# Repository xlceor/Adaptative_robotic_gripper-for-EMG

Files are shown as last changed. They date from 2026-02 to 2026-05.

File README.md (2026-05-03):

# PROJECT KHYMERA

## Modular Robotic Prosthetic System | Functional, Scalable, Real

---

## 🚀 TL;DR

A low-cost modular robotic prosthetic system built with real hardware, real iteration, and real-world constraints.

- Dual-servo optimized gripper  
- Fully functional prototype (V0 → V2)  
- Designed for future EMG control  
- Built with 3D printing + embedded systems  

---

## 🎥 Live Demonstration

0503 (1)(1)

This is not a concept.

This is a working system:
- Real movement  
- Real grip  
- Real control  

---

## 🧠 Overview

Project KHYMERA is a modular robotic prosthetic system designed to challenge the traditional approach to upper-limb prosthetics.

Instead of replicating the human hand, this project focuses on:

- Mechanical efficiency  
- Modularity  
- Accessibility  
- Scalability toward myoelectric control  

The result is a functional robotic gripper system built through iterative engineering, not theoretical design.

---

## 🛠️ System Architecture

### ⚙️ Mechanical System

- Parallel gripper design  
- Four-bar linkage mechanism  
- Dual servo actuation  
- Geometry optimized for full range of motion  

---
### 💻 Control system

#### Control Layer
Handles smooth motion interpolation between target and current positions:
- Real-time servo control loop (~20 ms)
- Dual-servo synchronized movement

#### Communication Layer
Provides external control and monitoring:
- REST API endpoints (`/servo`, `/ping`, `/demo`)
- WiFi Access Point mode
- Server-Sent Events (SSE) for real-time streaming

#### Telemetry Layer
Streams system diagnostics to the UI:
- Simulated temperature, voltage, load, vibration, ADC
- Designed to emulate real sensor behavior

#### State Layer
Maintains and broadcasts system state:
- Target vs current angle tracking
- Real-time synchronization with UI

#### UI Integration
Designed for real-time dashboard interaction:
- Low-latency feedback via SSE
- Compatible with advanced HUD-style interfaces

### 🔩 Manufacturing

- 3D Printing (FDM):
  - PLA → structural components  
  - TPU → flexible gripping surfaces  
- Rapid prototyping workflow  

---

### 🔌 Electronics

- ESP32-based control  
- Servo motors (MG996R)  
- Power system:
  - Dual 18650 batteries  
  - DC-DC regulator (XL4016)  
- Capacitor-based stabilization  

---

## 📁 Repository Structure
/mechanical/   → CAD files (V0, V1, V2)
/firmware/     → Embedded control code

---

## 🚨 The Problem

Modern prosthetics face critical limitations:

- High cost → inaccessible to many users  
- Mechanical complexity  
- Limited adaptability  

Even open-source solutions often struggle with:

- Inefficient actuation  
- Poor force transmission  
- Overreliance on biomimicry  

---

## 💡 The Approach

KHYMERA proposes a shift in design philosophy:

**From biomimicry → functional modularity**

Instead of replicating the human hand, the system is designed as:

- A robotic gripper module  
- Mechanically efficient  
- Easy to manufacture  
- Ready for integration into larger systems  

---

## 🔁 Development Process

Built through iterative engineering:

| Version | Purpose | Result |
|---|---|---|
| V0 | Validate mechanism | Functional proof of concept |
| V1 | Integrate actuation | Improved structure, limited motion |
| V2 | Optimize geometry | Full range of motion, stable operation |

### Key Improvements

- Enhanced motion transmission  
- Improved grip using TPU surfaces  
- Structural alignment refinements  

---

## 📊 Functional Capabilities

Validated through real-world testing:

- ✔ Stable opening and closing motion  
- ✔ Reliable object gripping  
- ✔ Adaptability to different object shapes  
- ✔ Improved friction via TPU contact surfaces  

---

## 🧪 Methodology

- Experimental + technological research approach  
- Iterative prototyping  
- Direct functional testing  
- Qualitative performance evaluation  

Follows a standard engineering loop:

**Design → Build → Test → Optimize**

---

## 🚀 Why This Project Matters

- Demonstrates real engineering execution  
- Focuses on accessibility and affordability  
- Bridges mechanics, electronics, and embedded systems  
- Designed under real-world constraints, not ideal conditions  

---

## 🧭 Future Work

- EMG signal acquisition (ESP32-S3)  
- Myoelectric control system  
- Force sensing integration  
- Closed-loop control  
- Full robotic arm system  
- Advanced materials and optimization  

---

## ⚡ Quick Start

1. 3D print components (PLA + TPU)  
2. Assemble mechanical structure  
3. Upload firmware to Arduino  
4. Power with regulated ~6.2V supply  

**Recommended:** basic experience with electronics and 3D printing  

---

## 👨‍💻 Author

Carlos Osorio  
Systems Builder | Robotics | Embedded Systems | Applied Engineering  

Focused on building systems that interact with the real world.

---

## ⚠️ Disclaimer

This project is an experimental prototype and is not intended for clinical use.

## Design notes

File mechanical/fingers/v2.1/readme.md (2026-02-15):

# TPU Finger Prototype v1.1

## Purpose
TPU finger of adaptable soft-robotic gripper. 

## Geometry
Right triangle base with parallel internal bending lines to allow controlled deformation.

## Material
TPU 95A

## Comments of the version
The base model still the same that the previous version, but the external wall -the one that is in contact with the object- now has texture, adding friction and gripping capacity. Even so, the thickness of the external wall was small.
## Next Steps
Test under real-life load to meassure the resistance of the finger.

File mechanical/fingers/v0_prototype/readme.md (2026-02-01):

# TPU Finger Prototype v0

## Purpose
Initial experiment to create a compliant finger using TPU, based on observations of similar models.

## Geometry
Right triangle base with parallel internal bending lines to allow controlled deformation.

## Material
TPU 95A

## Observations
Conceptual model. The thickness is based on approximations, but actual performance and future iterations will depend on prototyping.

## Next Step
3D print the model to test performance

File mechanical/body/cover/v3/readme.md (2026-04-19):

# Cover v3

## Purpose
Close the design and keep all internal components hidden, improving the aesthetics.

## Geometry
The shape was designed based on the body's design. It was divided into three parts, each corresponding to a section of the body. This allows for quicker access to a specific component if needed, without having to open the entire device.

## Material
PLA for testing

## Comments of the version
Due to time reasons, the body itself was not updated for the mounting points. In this version self-tapping screws was used to close the device without reprinting all the design. Also, some slots was added for better ventilation on components as the buck, and the servos, but also to keep acces to some components without removing the case, like the switch and the alimentation of ESP32.

## Next Steps
Update main body, verify issues, and roceed remodeling

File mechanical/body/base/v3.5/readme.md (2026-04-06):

# Base v3.5

## Purpose
Base of the four-bar linkage. It serves as a support and for storing the electronics, including the servos, buck converter, and MCU.

## Geometry
The shape was designed in base of the structure of 2 servos tandem-mounted and the module Xl4016, with sections on the sides to store MCU, power supply board, and the batteries

## Material
PLA for testing

## Comments of the version
Integred the new sections on this version. It appears to work fine. But, the reduction still as a problem. I think the best way to proceed is redesign the original "box" to reduce the space between servos, print gears for each one and conect both mechanically, and redesign the finger to adapt to the new rotation.

## Next Steps
Verify issues, and proceed remodeling

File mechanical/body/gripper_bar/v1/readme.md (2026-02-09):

# Linkage bar v1

## Purpose
link base that connects the TPU finger to the base via the mechanism.

## Geometry
The shape was designed to reduce weight while maintaining strength. 

## Material
Currently PLA. In future versions, the material will be remplaced with PETG

## Comments of the version
This model is the first to be tested under real-world conditions. Unlike the previous version, the center-to-center distance is greater for increased gripping capacity. Additionally, the number of screw holes has been increased to two, eliminating the problem of the previous version (where the head rotated using the center screw as an axis). Furthermore, the head geometry has been adapted to reduce weight while maintaining strength.

## Next Steps
Keep testing to see the response of the material under weight and load.

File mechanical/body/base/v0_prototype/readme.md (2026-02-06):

# Base v0

## Purpose
Base of the four-bar linkage. It serves as a support and for storing the electronics, including the servo.

## Geometry
The shape was designed to priorize stability. In this version, the base only acts as a support for prototyping.

## Material
PLA or PETG, depending on testing

## Observations
Conceptual model. The design are not tested on real life. I'll adjust the lenght and shape depending on results of testing
## Next Step
3D print the model to test shape and validate size.

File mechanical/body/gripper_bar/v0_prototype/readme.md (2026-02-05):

# Linkage bar v0

## Purpose
Initial link base that connects the TPU finger to the base via the mechanism.

## Geometry
The shape was designed to reduce weight while maintaining strength.

## Material
PLA or PETG, depending on testing

## Observations
Conceptual model. I'll adjust the form to be more strong and use less filament in future versions.
## Next Step
3D print the model to test performance

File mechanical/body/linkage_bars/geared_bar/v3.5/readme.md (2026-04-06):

# Geared bars v3.5

## Purpose
principal bars of the mechanism. Translates the servo output to the open/closing mechanism of the gripper. 

## Geometry
Due to the transmission is located in the rear area, while mantaining the same geometry, it can provide a bigger range of motion.

## Material
PLA for testing

## Comments of the version
In this version, I increased the height of the slot of the screw to provide more height, and prevent the mechanism from getting stuck
## Next Steps

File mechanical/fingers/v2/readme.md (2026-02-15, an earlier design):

# TPU Finger Prototype v1.1

## Purpose
TPU finger of adaptable soft-robotic gripper. 

## Geometry
Right triangle base with parallel internal bending lines to allow controlled deformation.

## Material
TPU 95A

## Comments of the version
Based on the previous observations, the stiffness of the finger was reduced by making the internal walls thinner. Also, the upper tip was rounded, reducing sharpness and the filament used. Even so, the wall used to grip objects was flat, reducing gripping ability. 
## Next Steps
Give the external wall texture to add gripping capacity

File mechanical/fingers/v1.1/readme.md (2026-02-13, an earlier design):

# TPU Finger Prototype v1.1

## Purpose
TPU finger of adaptable soft-robotic gripper. 

## Geometry
Right triangle base with parallel internal bending lines to allow controlled deformation.

## Material
TPU 95A

## Comments of the version
According to observations, the finger proved to be quite rigid, primarily due to the support lines parallel to the longer leg of the triangle, which is the area where the object is gripped. In this version, the orientation, number, and thickness of the parallel lines were modified, tilting them at a 50-degree angle to the base, allowing for controlled deformation. However, this version still exhibits considerable rigidity, causing more fragile objects to tend to break or deform when the claw closes. Also, the upper tip can be somewhat sharp and still represents wasted material.

## Next Steps
Adjust the thickness of the internal walls to reduce rigidity, and round the upper tip.

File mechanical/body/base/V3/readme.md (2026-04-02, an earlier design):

# Base v3

## Purpose
Base of the four-bar linkage. It serves as a support and for storing the electronics, including the servos and MCU.

## Geometry
The shape was designed in base of the structure of 2 servos tandem-mounted and the module Xl4016.

## Material
PLA for testing

## Comments of the version
The total torque was insufficient for the aplication needed. So, the design was remodeled based on 2 servos working together, hopefully multiplying the torque by two.
## Next Steps
Adapt the model to manage all the electronics

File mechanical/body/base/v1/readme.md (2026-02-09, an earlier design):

# Base v1

## Purpose
Base of the four-bar linkage. It serves as a support and for storing the electronics, including the servo.

## Geometry
The shape was designed in base of the structure of the servo, to link easily and mantain streght.

## Material
PLA or PETG, depending on testing

## Comments of the version
As readed before, the shape was modeled in base of the servomotor, a MG996R, to fit well on the servo and let the servo output at the base level of the piece. The piece was designed for use gears.
## Next Steps
Adapt the model to add stability.

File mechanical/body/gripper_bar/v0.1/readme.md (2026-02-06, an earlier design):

# Linkage bar v0.1

## Purpose
link base that connects the TPU finger to the base via the mechanism.

## Geometry
The shape was designed to reduce weight while maintaining strength. 

## Material
PLA or PETG, depending on testing

## Observations
Unlike the previous model, this version consists of two separate pieces for improved printing. The pieces are connected by a screw for added stability. Additionally, the head width has been reduced for compatibility with screws.

## Next Step
3D print the model to test performance

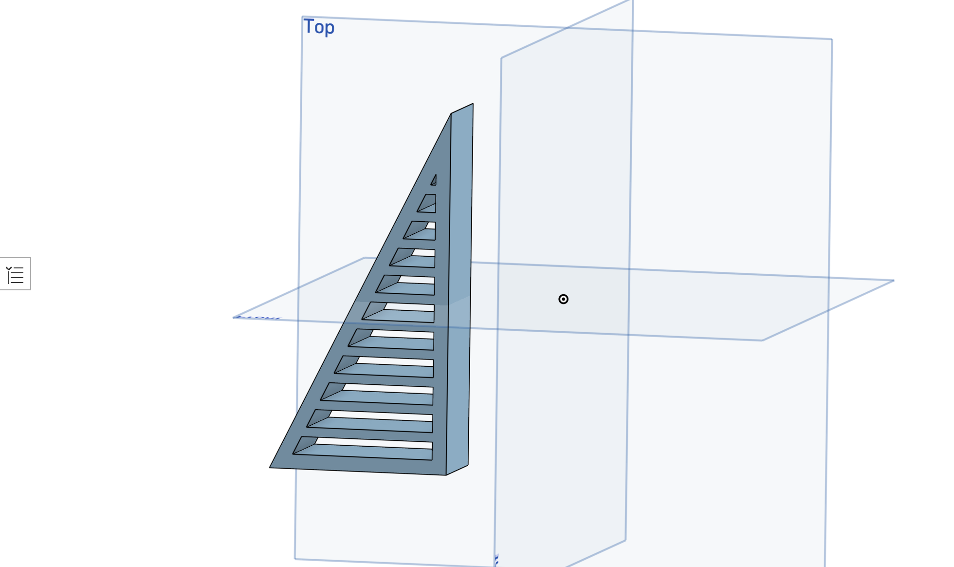
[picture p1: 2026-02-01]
mechanical/fingers/v0_prototype/screenshot.png

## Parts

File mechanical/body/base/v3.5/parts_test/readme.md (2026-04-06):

# Base v3.5 - part test

## Purpose
New section of the base that will store the logic. There, will be stored the ESP32 as MCU, and a custom welded board to manage the power supply

## Geometry
The shape was designed in base of the structure of the ESP32-S3 wroom, and a custom board. Also, a slot will be added to power the ESP32 and re-program. 

## Material
PLA for testing

## Comments of the version
These are two tests. In the first one, I didn't realize that a wall was blocking the ESP32's entry because the antenna was sticking out. So I remodel, and the second test worked correctly.

## Next Steps
Add the module to the base

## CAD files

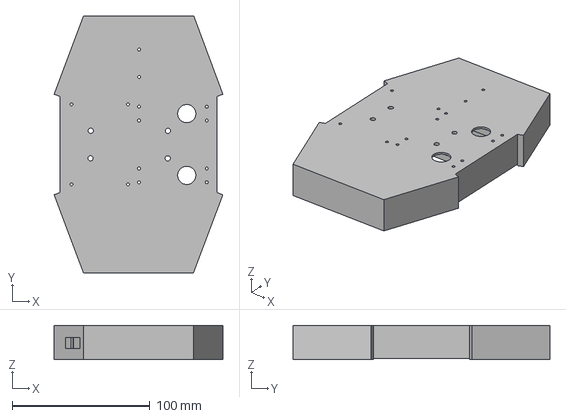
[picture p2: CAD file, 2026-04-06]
mechanical/body/base/v3.5/base.step
122.4 x 186.4 x 25.0 mm

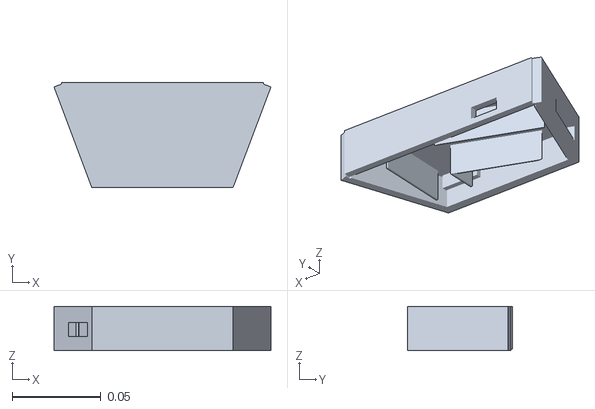
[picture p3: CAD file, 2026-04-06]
mechanical/body/base/v3.5/parts_test/test_2.stl
0.122 x 0.0592 x 0.025

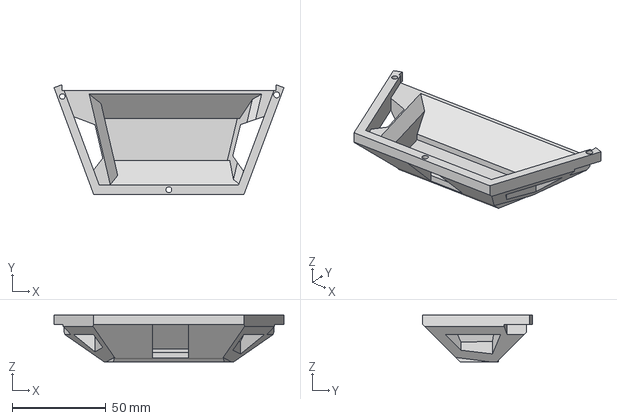
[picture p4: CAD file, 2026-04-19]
mechanical/body/cover/v3/left.step
122.4 x 58.3 x 25.0 mm

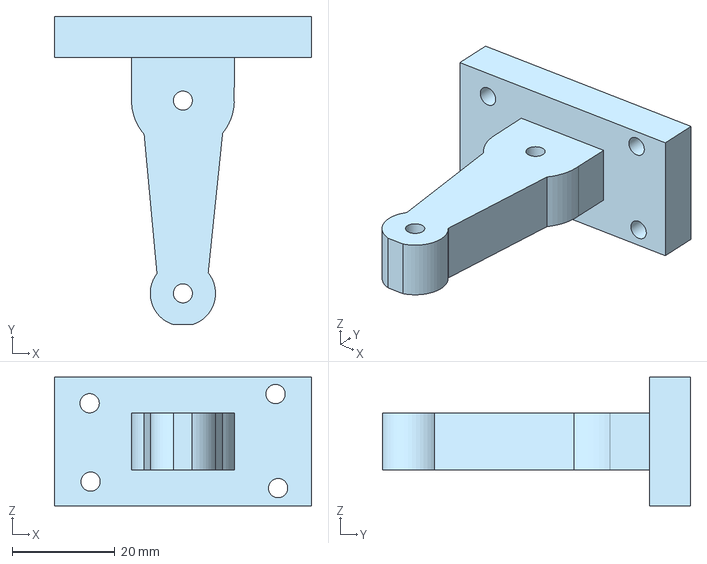
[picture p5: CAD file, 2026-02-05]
mechanical/body/gripper_bar/v0_prototype/linkage_bar.step
50.0 x 60.0 x 25.0 mm

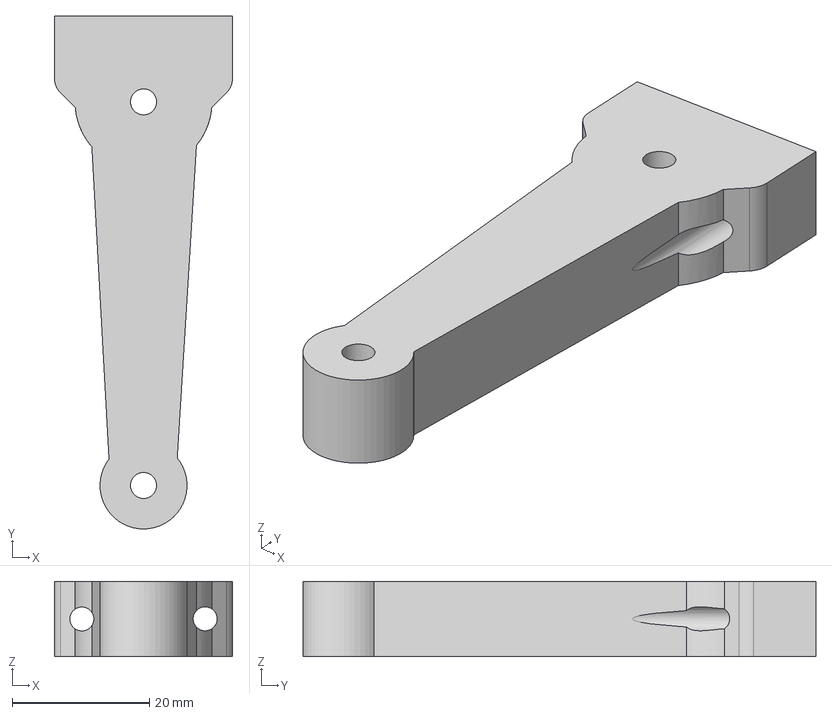
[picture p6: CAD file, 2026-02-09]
mechanical/body/gripper_bar/v1/body.step
26.0 x 74.9 x 11.0 mm

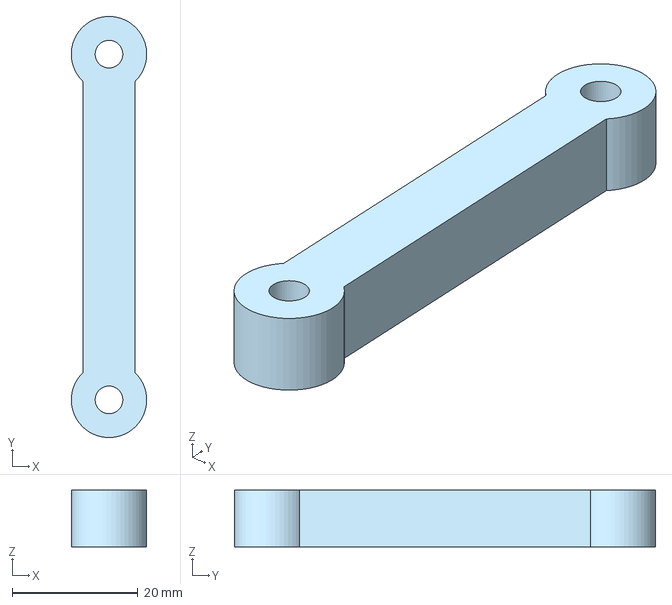
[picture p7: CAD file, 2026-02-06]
mechanical/body/linkage_bars/support_bar/v0_prototype/support_bar.step
12.0 x 67.0 x 9.00 mm

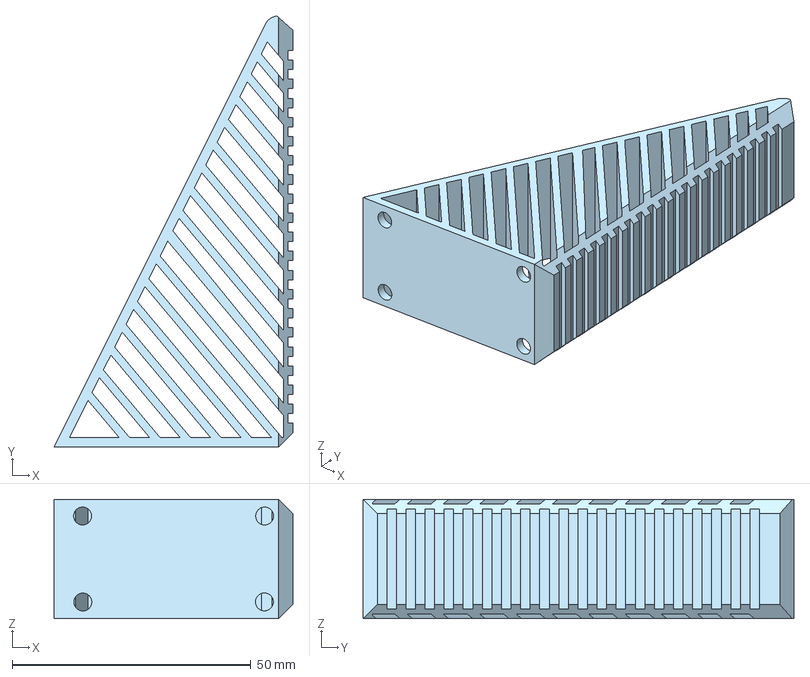
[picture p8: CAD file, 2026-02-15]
mechanical/fingers/v2.1/finger.step
50.0 x 90.2 x 25.0 mm

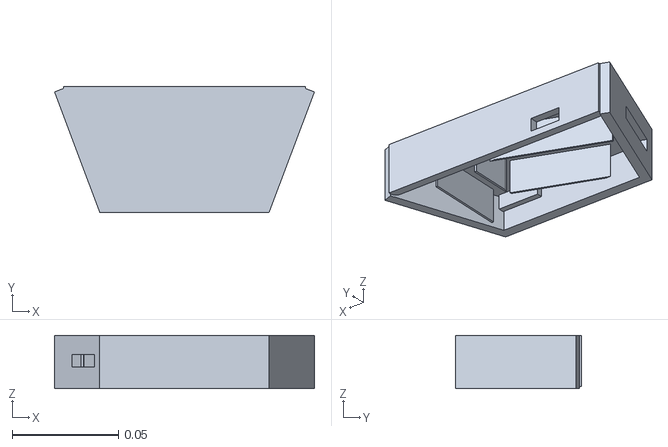
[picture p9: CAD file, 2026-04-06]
mechanical/body/base/v3.5/parts_test/test_1.stl
0.122 x 0.0592 x 0.025

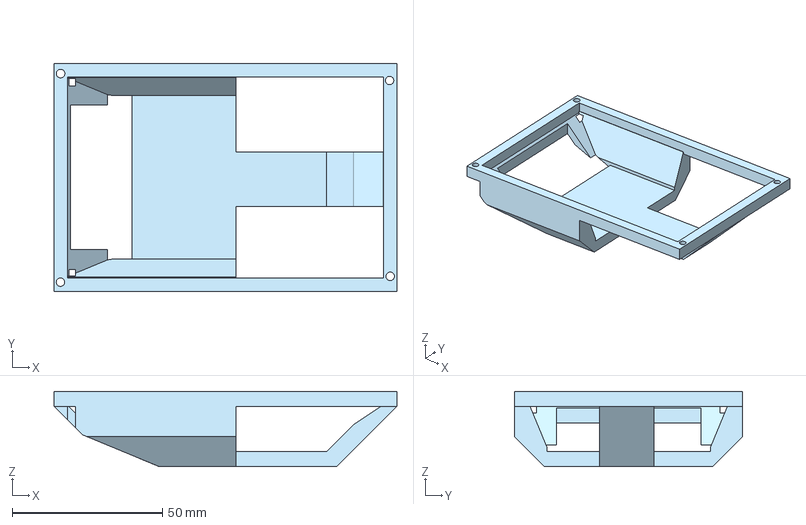
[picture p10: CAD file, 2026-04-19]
mechanical/body/cover/v3/center.step
114.0 x 75.8 x 25.0 mm

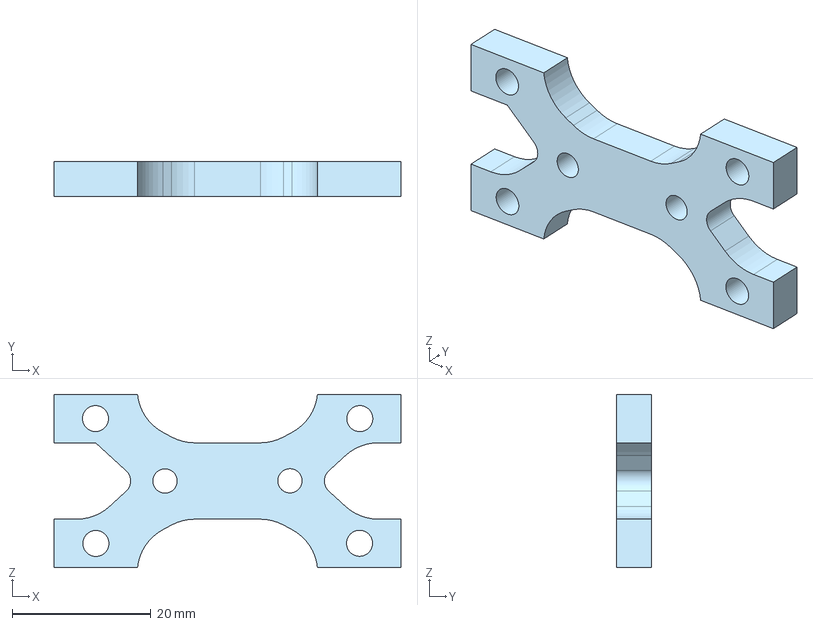
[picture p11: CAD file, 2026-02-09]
mechanical/body/gripper_bar/v1/head.step
50.0 x 5.00 x 25.0 mm

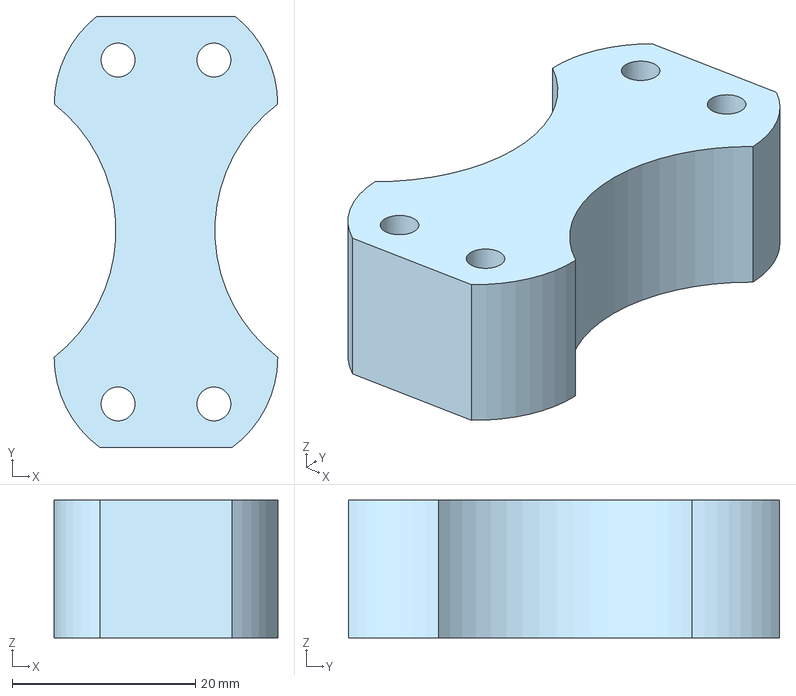
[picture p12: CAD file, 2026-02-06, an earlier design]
mechanical/body/base/v0_prototype/base.step
24.4 x 47.0 x 15.0 mm

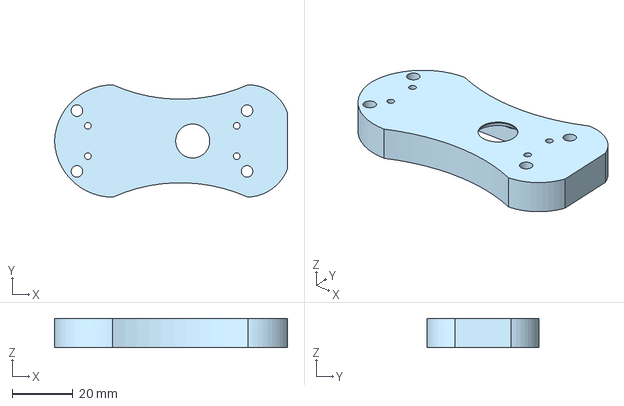
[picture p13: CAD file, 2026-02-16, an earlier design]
mechanical/body/base/v1.5/base.step
76.7 x 37.0 x 9.60 mm

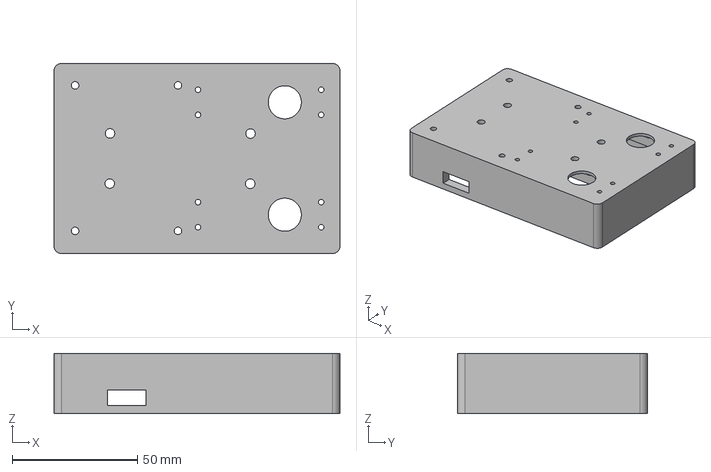
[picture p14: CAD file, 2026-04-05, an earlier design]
mechanical/body/base/v3.1/base.step
114.0 x 75.8 x 24.0 mm

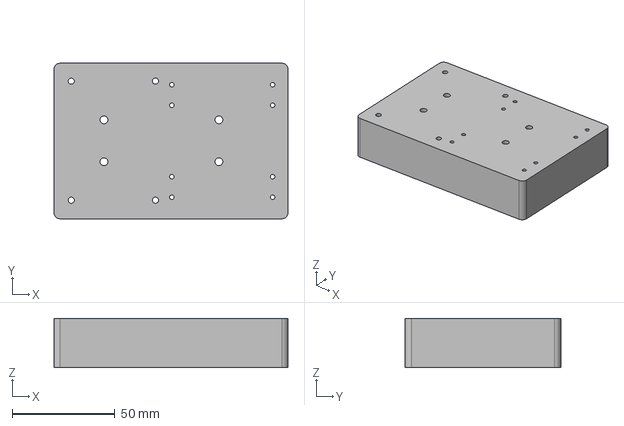
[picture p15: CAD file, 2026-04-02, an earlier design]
mechanical/body/base/V3/base.step
114.0 x 75.8 x 24.0 mm

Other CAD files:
mechanical/body/cover/v3/right.step
mechanical/body/base/v1/base.step
mechanical/body/gripper_bar/v0.1/body.step
mechanical/body/linkage_bars/geared_bar/v1.1/gear_servo.stl
mechanical/body/base/V3/base.stl
mechanical/body/base/v0_prototype/base.stl
mechanical/body/base/v1.5/base.stl
mechanical/body/base/v1/base .3mf
mechanical/body/base/v1/base .stl
mechanical/body/base/v3.1/base.stl
mechanical/body/base/v3.5/base.stl
mechanical/body/cover/v3/center.stl
mechanical/body/cover/v3/left.stl
mechanical/body/cover/v3/right.stl
mechanical/body/gripper_bar/v0.1/body.stl
mechanical/body/gripper_bar/v0.1/head.step
mechanical/body/gripper_bar/v0.1/head.stl
mechanical/body/gripper_bar/v0_prototype/linkage_bar.stl
mechanical/body/gripper_bar/v1/body.stl
mechanical/body/gripper_bar/v1/head.stl
mechanical/body/linkage_bars/geared_bar/v1/gear_servo.step
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

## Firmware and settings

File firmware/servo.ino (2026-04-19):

#include <WiFi.h>
#include <ESPAsyncWebServer.h>
#include <ArduinoJson.h>
#include <ESP32Servo.h>
#include <math.h>

const char* ssid = "ESP32-Control";
const char* password = "12345678";

AsyncWebServer server(80);
AsyncEventSource events("/events");

Servo servo1;
Servo servo2;

#define SERVO1_PIN 15
#define SERVO2_PIN 16
#define offLed 17
#define onLed 18

volatile float targetAngle  = 90.0f;
float          currentAngle = 90.0f;


float fakeTemp() {
  static float value = 20.0;
  static bool up = true;
  value += (up ? 0.2 : -0.2);
  if (value >= 30.0) up = false;
  if (value <= 20.0) up = true;
  return value;
}

int fakeADC() {
  static int value = 0;
  static bool up = true;
  value += (up ? 20 : -20);
  if (value >= 4095) up = false;
  if (value <= 0) up = true;
  return value;
}

void setup() {
  // -Config-
  Serial.begin(115200);
  Serial.print("[system] Booting...");

  ESP32PWM::allocateTimer(0);
  ESP32PWM::allocateTimer(1);
  
  servo1.setPeriodHertz(50); 
  servo2.setPeriodHertz(50);
  
  servo1.attach(SERVO1_PIN, 500, 2400); 
  servo2.attach(SERVO2_PIN, 500, 2400);
  
  pinMode(offLed, OUTPUT);
  pinMode(onLed, OUTPUT);

  // -SoftAP-
  Serial.print("[Wifi] Connecting...");
  WiFi.softAP(ssid, password);

  IPAddress IP = WiFi.softAPIP();

  Serial.println("\n [Wifi] Conected!");
  Serial.print("[Wifi] Server IP: ");
  Serial.println(IP);

  digitalWrite(offLed, LOW);
  digitalWrite(onLed, HIGH);

  // -CORS-
  DefaultHeaders::Instance().addHeader("Access-Control-Allow-Origin", "*");
  DefaultHeaders::Instance().addHeader("Access-Control-Allow-Methods", "GET, POST, OPTIONS");
  DefaultHeaders::Instance().addHeader("Access-Control-Allow-Headers", "Content-Type");

  // -SSE-
  events.onConnect([](AsyncEventSourceClient* client) {
    Serial.printf("[SSE] Client connected, id=%u\n", client->lastId());
    client->send("connected", "status", millis());
  });

  server.addHandler(&events);

  server.on("/servo", HTTP_POST,
  [](AsyncWebServerRequest* request){},
  nullptr,
  [](AsyncWebServerRequest *request, uint8_t *data, size_t len, size_t index, size_t total) {

    StaticJsonDocument<64> doc;

    if (deserializeJson(doc, data, len)) {
      request->send(400, "application/json", "{\"error\":\"invalid JSON\"}");
      return;
    }

    if(doc.containsKey("servo")){
      targetAngle = constrain((float)doc["servo"], 0.0f, 180.0f);
      Serial.printf("[Servo] -> %.1f\n", targetAngle);
    }

    request->send(200, "application/json", "{\"ok\":true}");
  }
);
  
  server.on("/servo", HTTP_OPTIONS, [](AsyncWebServerRequest* request) {
    request->send(204);
  });

  server.begin();
}

void loop() {
  static unsigned long last = 0;
  if (millis() - last > 20) {
    last = millis();

    float diff = targetAngle - currentAngle;

    if(fabs(diff) > 0.5f)
      currentAngle += diff * 0.15f;
    else
      currentAngle = targetAngle;

    servo1.write((int)currentAngle);
    servo2.write(180 - (int)currentAngle);
  }

  static unsigned long lastTelemetry = 0;
  if (millis() - lastTelemetry > 1000) {
    lastTelemetry = millis();

    StaticJsonDocument<256> doc;
    doc["temp"] = fakeTemp();
    doc["adc"]  = fakeADC();

    String output;
    serializeJson(doc, output);

    events.send(output.c_str(), "telemetry", millis());
  }
}

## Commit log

2026-02-01 Finished 3D model of finger v0
    [finger.step, finger.stl]
2026-02-05 created the v_0 of linkage_base
    [linkage_bar.step, linkage_bar.stl]
2026-02-06 Improved linkage bar
    [body.step, body.stl, head.step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]
2026-02-06 Created the base
    [base.step, base.stl]
2026-02-06 Created support bar
    [body.step, body.stl, head.step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]
2026-02-09 Re-modeled the mechanism.
    [base .stl, base- Part 12.step, body.step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]
2026-02-09 Add documentation of all new files
    [base - Spur gear (14 teeth).stl, base .3mf, base.step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]
2026-02-13 Created 1.1 of finger
    [base - Spur gear (14 teeth).stl, finger.step, finger.stl]
2026-02-15 Added V2 and V2.1 fingers
    [finger.step, finger.stl]
2026-02-15 added v2 support bars
    [left.step, left.stl, right.step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]
2026-02-16 added support bars
    [base.step, base.stl, geared_a.step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]
2026-02-28 Adjust tolerances
    [geared_a.step, geared_a.stl, geared_b.step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]
2026-03-16 v2.0 - First functional prototype ended
2026-04-02 Start developing V3
    chore: add major offline progress (CAD redesign, electronics integration, prototypes)
    [base.step, base.stl]
2026-04-05 finished docs of 3.1
    [base.step, base.stl, left.step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]
2026-04-06 Finish uploading of V3.5
    [base.step, base.stl, left.step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]
2026-04-08 Update firmware to add wireless control
2026-04-09 Added leds as connection indicators
2026-04-19 Added covers
    [center.step, center.stl, left.step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]
2026-04-19 Switch to SSE, SoftAP; smooth servo motion
    Due to problems with Websockets, the architecture was switched to SSE and HTTP polling
    [servo.ino]
2026-05-03 Update control system from Arduino to ESP32
